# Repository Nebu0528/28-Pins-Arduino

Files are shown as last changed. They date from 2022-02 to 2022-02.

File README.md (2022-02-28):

# 28-Pins-Arduino!
Created a Replica of an Arduino Uno Board with modifications (listed below)

●	Utilized Altium Designer to create schematic, 3D components, PCB model and enhanced board by adding a user button, micro-USB (to allow charging from other devices) and a DFU Disable jumper.

●	Modified 16U2 and 328P Reset Pins to be driven through an open drain buffer meaning the RESET quality has been improved and allows for debugging microcontrollers through the dWire. 

●	Documented and replicated all elements of the design process including costs, schematic, assembly drawing and 3D PCB Model. 

PDF Files can be found in the folders attached above

## PCB

## 3D Model


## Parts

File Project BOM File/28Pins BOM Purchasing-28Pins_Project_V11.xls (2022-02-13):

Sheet: Part List Report
 | Component list |  |  | 28Pins BOM Purchasing for Project [28Pins_Project_V11.PrjPcb] (PCB Document : V1I1PCB.PcbDoc)
 | Source Data From: | 28Pins_Project_V11.PrjPcb |  |  | Contact: |  |  |  | Generated by:
 | Project: | 28Pins_Project_V11.PrjPcb
 | Variant: | None |  |  |  |  |  |  | FEDEVEL
 | Report Date: | 2022-02-01 | 5:48 PM |  |  |  |  |  | http://www.fedevel.com
 | Print Date: | 2022-02-01 | 18:30:28
# | Category | Manufacturer 1 | Manufacturer Part Number 1 | #Column Name Error:' Package / Case | Description | Quantity | Supplier 1 | Supplier Part Number 1 | Supplier Order Qty 1 | Supplier Stock 1 | Supplier Unit Price 1 | Supplier Subtotal 1 | Supplier Currency 1
1 | Aluminum Electrolytic Capacitors | Panasonic | EEE-1AA101WR |  | Cap Aluminum 100uF 10V 20% (5 X 5.4mm) SMD 50mA 1000 hr 85°C T/R | 2 | Digi-Key | PCE3867CT-ND | 20 | 0 | 0.27 | 5.30 | USD
2 | Ceramic Capacitors | TDK | C2012X5R1C106M125AC |  | CERAMIC CAPACITOR, 10UF, 16V, X5R, 20%, 0805, FULL REEL; Product Range:C Series; Capacitance:10 F; Capacitance Tolerance: 20%; Dielectric Characteristic:X5R; Voltage Rating:16V; Ceramic Capacitor Case:0805 [2012 Metric]; MSL:- ;RoHS Compliant: Yes | 7 | Digi-Key | 445-4115-1-ND |  | 0
3 | Ceramic Capacitors | TDK | C2012X7R1H104K085AA |  | C Series 0805 0.1 uF 50 V ±10 % Tolerance X7R SMT Multilayer Ceramic Capacitor | 19 | Newark | 87R4037 | 190 | 12000 | 0.03 | 4.94 | USD
4 | Ceramic Capacitors | TDK | C2012X5R1E105K125AA |  | TDK - C2012X5R1E105K125AA - SMD Multilayer Ceramic Capacitor, 1 µF, 25 V, 0805 [2012 Metric], ± 10%, X5R, C Series | 1 | Digi-Key | 445-1419-1-ND | 10 | 1537 | 0.16 | 1.58 | USD
5 | Ceramic Capacitors | KEMET | C0805C180J5GACTU |  | Cap Ceramic 18pF 50V C0G 5% SMD 0805 125C Paper T/R | 4 | Digi-Key | 399-C0805C180J5GAC7800TR-ND |  | 87418 |  |  | USD
6 | LEDs | Osram Opto | LGL29K-G2J1-24-Z |  | LED Single Chip Green 570nm 20mA 2-Pin 0603 T/R | 1 | Digi-Key | 475-2709-1-ND |  | 0
7 | Uncategorized | Osram Opto | LOL29K-H2K1-24-Z |  | Smartled Orange Lc | 1 | Digi-Key | 475-2740-1-ND |  | 0
8 | Schottky Diodes | ON Semiconductor / Fairchild | BAT54HT1G |  | Small Signal Schottky Diode, Single, 30 V, 200 Ma, 800 Mv, 600 Ma, 150 C | 2 | Digi-Key | BAT54HT1GCT-ND |  | 0
9 | Ferrite Beads and Chips | TDK | MPZ2012S601AT000 |  | Ferrite Beads Multi-Layer Power 600Ohm 25% 100MHz 2A 100mOhm DCR 0805 T/R | 3 | Digi-Key | 445-2206-6-ND | 30 | 0 | 0.09 | 2.71 | USD
10 | Headers and Wire Housings | Harwin | M20-7820842 |  | 2.54mm (0.1") Pitch SIL Vertical PC Tail Socket Assembly, selective gold + tin, 8 contacts | 2 | Newark | 55K6995 | 20 | 316 | 0.42 | 8.48 | USD
11 | Headers and Wire Housings | Harwin | M20-7820646 |  | 2.54mm (0.1") Pitch SIL Vertical PC Tail Socket Assembly, tin, 6 contacts | 1 | Digi-Key | 952-1809-ND | 10 | 1020 | 1.17 | 11.70 | USD
12 | Headers and Wire Housings | Harwin | M20-7821046 |  | 2.54mm (0.1") Pitch SIL Vertical PC Tail Socket Assembly, tin, 10 contacts | 1 | Digi-Key | 952-1847-ND | 10 | 33 | 1.47 | 14.70 | USD
13 | Headers and Wire Housings | Amphenol ICC / FCI | 67997-106HLF |  | Conn Unshrouded Header HDR 6 POS 2.54mm Solder ST Top Entry Thru-Hole BergStik® Bulk | 2 | Digi-Key | 609-3393-ND | 20 | 1491 | 1.90 | 38.00 | USD
14 | USB Connectors | Amphenol ICC / FCI | 10118193-0001LF |  | FCI Right Angle Surface Mount Mount Female USB Connector; 100 V ac; 1.8A | 1 | Digi-Key | 609-4616-1-ND | 10 | 565 | 0.42 | 4.20 | USD
15 | Headers and Wire Housings | Amphenol ICC / FCI | 68000-103HLF |  | Conn Unshrouded Header HDR 3 POS 2.54mm Solder ST Top Entry Thru-Hole BergStik® Automotive Bulk | 2 | Digi-Key | 609-3461-ND | 20 | 57459 | 0.31 | 6.16 | USD
16 | Connectors | Amphenol ICC / FCI | 68602-204HLF |  | Conn Unshrouded Header HDR 4 POS 2.54mm Solder ST Top Entry Thru-Hole BergStik® Bulk | 1 | Digi-Key | 609-3369-ND | 10 | 30 | 0.29 | 2.87 | USD
17 | Headers and Wire Housings | Amphenol ICC / FCI | 68001-204HLF |  | Conn Unshrouded Header HDR 4 POS 2.54mm Solder ST Thru-Hole Bag | 1 | Digi-Key | 609-3402-ND | 10 | 9015 | 0.40 | 3.95 | USD
18 | Fixed Inductors | KEMET | L1210R2R2MDWIT |  | Inductor RF Chip Wirewound 2.2uH 20% 100KHz 1.13A 0.104Ohm DCR 1210 T/R | 1 | Digi-Key | 399-9598-1-ND | 10 | 16332 | 0.44 | 4.37 | USD
19 | Connectors | Sullins | QPC02SXGN-RC |  | 2 Position 2.54 mm Centerline Single Circuit Open Top Jumper | 3 | Digi-Key | S9337-ND | 30 | 1685454 | 0.04 | 1.22 | USD
20 | Chip SMD Resistors | Yageo | RC0805JR-07100KL |  | Res General Purpose Thick Film 0805 100k Ohm 5% 1/8W ±100ppm/°C Molded Paper T/R | 1 | Digi-Key | 311-100KARCT-ND | 10 | 7 | 0.04 | 0.36 | USD
21 | Chip SMD Resistors | Yageo | RC0805FR-07560RL |  | Res General Purpose Thick Film 0805 560 Ohm 1% 1/8W ±100ppm/°C Molded Paper T/R | 5 | Digi-Key | 311-560CRCT-ND | 50 | 1559 | 0.04 | 2.10 | USD
22 | Chip SMD Resistors | Yageo | RC0805FR-0710KL |  | Res SMD 0805 10K 1% 0.125W T.C.100PPM | 6 | Digi-Key | 311-10.0KCRTR-ND |  | 873570 |  |  | USD
23 | Chip SMD Resistors | Yageo | RC0805FR-0722RL |  | Res SMD 0805 22R 1% 0.125W T.C.100PPM | 7 | Digi-Key | 311-22.0CRTR-ND |  | 104135 |  |  | USD
24 | Chip SMD Resistors | Yageo | RC0805JR-070RL |  | RC Series 0805 0.125 W 0 Ohm Jumper Surface Mount Thick Film Chip Resistor | 4 | Digi-Key | 311-0.0ARTR-ND |  | 2348866 |  |  | USD
25 | Chip SMD Resistors | Yageo Phycomp | RC0805FR-071ML |  | Res Thick Film 0805 1M Ohm 1% 0.125W(1/8W) ±100ppm/C Pad SMD T/R | 2 | Digi-Key | 311-1.00MCRTR-ND |  | 822877 |  |  | USD
26 | Chip SMD Resistors | Yageo | RC0805FR-071KL |  | Res Thick Film 0805 1KOhm 1% 0.125W(1/8W) 100ppm/C Epoxy Pad SMD T/R | 3 | Digi-Key | 311-1.00KCRTR-ND |  | 5035485 |  |  | USD
27 | Connectors | 3M | 4828-3004-CP |  | Socket DIP 28Cnts DualWipe 0.3InSpc. PhosphorBronze Nickel KinkedTail 4800Series | 1 | Digi-Key | 3M5480-ND | 10 | 8654 | 0.76 | 7.62 | USD
28 | Pushbutton Switches | TE Connectivity | FSM4JH |  | Switch Tactile OFF (ON) SPST Round Button PC Pins 0.05A 24VDC 1.57N Thru-Hole Loose | 2 | Digi-Key | 450-1650-ND | 20 | 136581 | 0.11 | 2.26 | USD
29 | Microcontrollers | Microchip | ATMEGA328P-PU |  | ATMEGA328P-PU; 8 bit Microcontroller AVR 20MHz 1; 32kb Flash; 2kb RAM; I2C SPI 2 | 1 | Allied Electronics | 70332157 |  | 0
30 | Microcontrollers | Microchip / Atmel | ATMEGA16U2-AU |  | 8-bit AVR MCU, 16 KB, 512 Bytes, 16 MHz, 2.7 to 5.5V, TQFP-32, RoHS | 1 | Arrow Electronics | ATMEGA16U2-AU |  | 0
31 | Voltage Regulators - Linear | Texas Instruments | TL1963A-33DCQR |  | LDO Regulator Pos 3.3V 1.5A 6-Pin(5+Tab) SOT-223 T/R | 1 | Digi-Key | 296-24534-1-ND | 10 | 0 | 3.25 | 32.52 | USD
32 | Logic Gates | Texas Instruments | SN74AHC1G09DBVR |  | Single 2-input, 2-V to 5.5-V AND gate with open-drain outputs 5-SOT-23 -55 to 125 | 4 | Digi-Key | 296-29202-1-ND | 40 | 0 | 0.31 | 12.46 | USD
33 | Crystals | Abracon | ABM7-16.000MHZ-D2Y-T |  | Crystal 16MHz ±20ppm (Tol) ±30ppm (Stability) 18pF FUND 50Ohm 2-Pin Mini-CSMD T/R | 2 | Digi-Key | 535-9840-1-ND | 20 | 0 | 0.77 | 15.46 | USD
34 | Varistors | Bourns | CG0603MLC-05E |  | ESD Suppressor Multilayer Varistor 5V Automotive 2-Pin Case 0603(1608Metric) T/R | 2 | Digi-Key | CG0603MLC-05ECT-ND | 20 | 0 | 0.35 | 6.96 | USD
 |  |  |  |  |  | 97 |  |  | 580 |  |  | 189.92
Approved |  |  |  | Notes: Some parts may no longer be available at the time of this project
 |  |  |  |  |  | 10 | pcs: | Total |  | 189.92 |  | USD
 |  |  |  |  |  |  |  | Price for 1pcs |  | 18.99 |  | USD

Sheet: Project Information
Project Full Path | C:\Users\Neel Bullywon\Desktop\Desktop\UWARG Bootcamp\28Pins_Project_V11\28Pins_Project_V11.PrjPcb
Project Filename | 28Pins_Project_V11.PrjPcb
Variant Name | None
Data-Source Filename | 28Pins_Project_V11.PrjPcb
Data-Source Full Path | C:\Users\Neel Bullywon\Desktop\Desktop\UWARG Bootcamp\28Pins_Project_V11\28Pins_Project_V11.PrjPcb
Title | 28Pins BOM Purchasing for Project [28Pins_Project_V11.PrjPcb] (PCB Document : V1I1PCB.PcbDoc)
Total Quantity | 97
Report Time | 5:48 PM
Report Date | 2022-02-01
Report Date & Tine | 2022-02-01 5:48 PM
Output Name | 28Pins BOM Purchasing
Output Type | BomReport
Output Generator Name | BOM
Output Generator Description | Bill of Materials

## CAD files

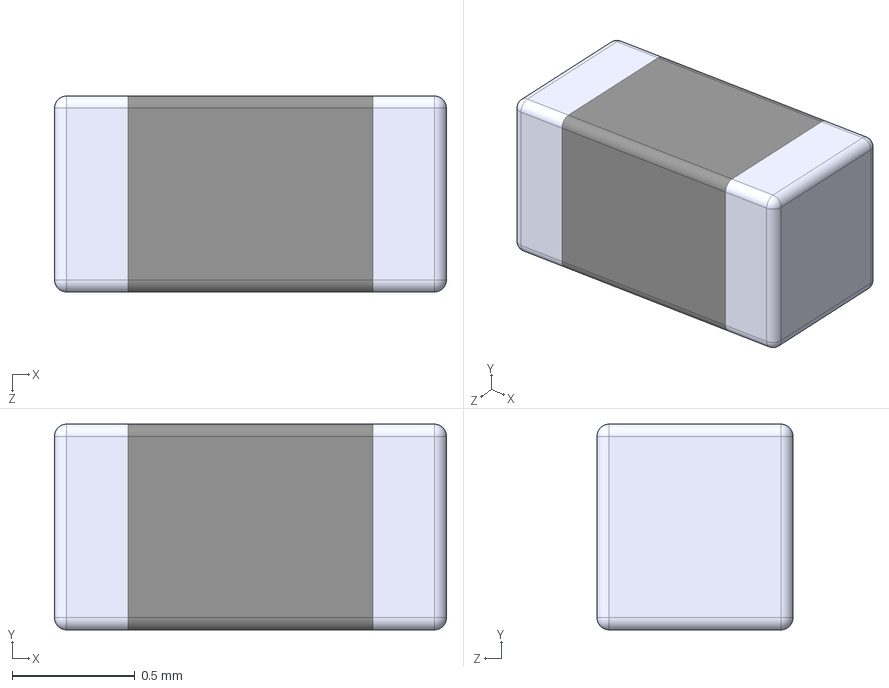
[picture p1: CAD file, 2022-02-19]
3D Component Models/R0603.step
1.60 x 0.84 x 0.8 mm

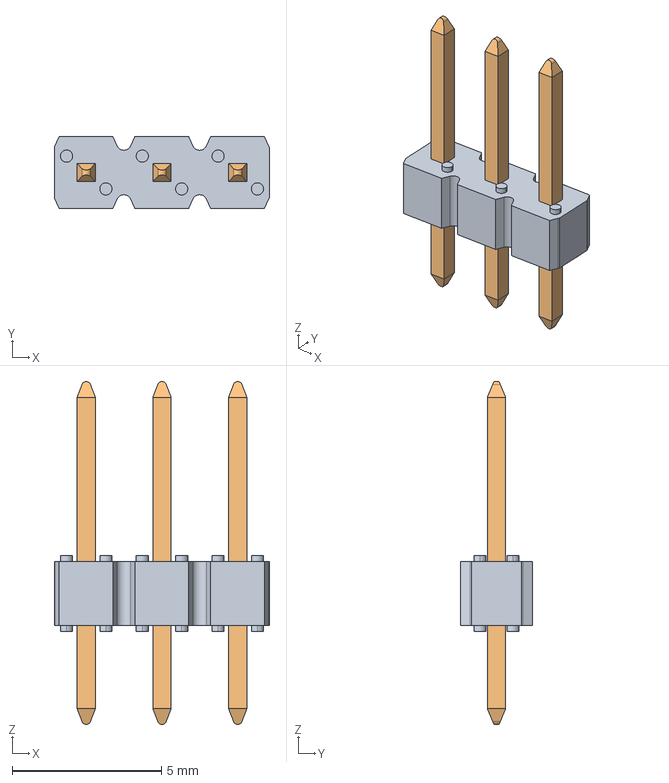
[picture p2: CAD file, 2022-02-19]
3D Component Models/HDR_1x3_White.stp
7.22 x 2.41 x 11.5 mm
77310_Y16 x 3

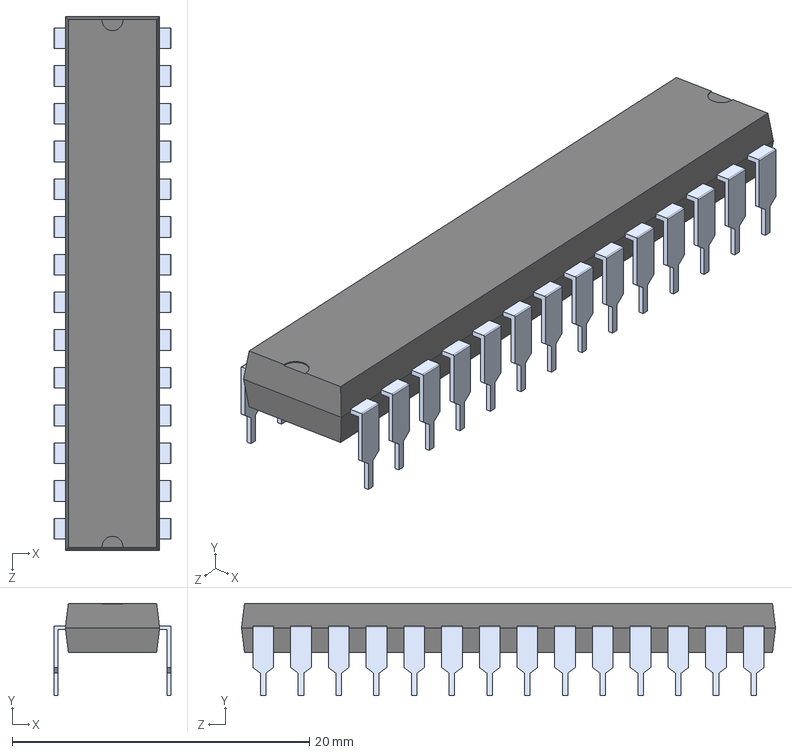
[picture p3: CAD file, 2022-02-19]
3D Component Models/28 pin dip.step
7.87 x 6.22 x 35.9 mm

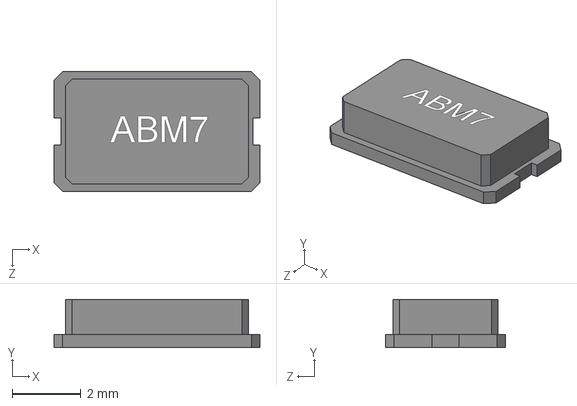
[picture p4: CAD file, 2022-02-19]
3D Component Models/ABM7.STEP
5.99 x 1.40 x 3.51 mm

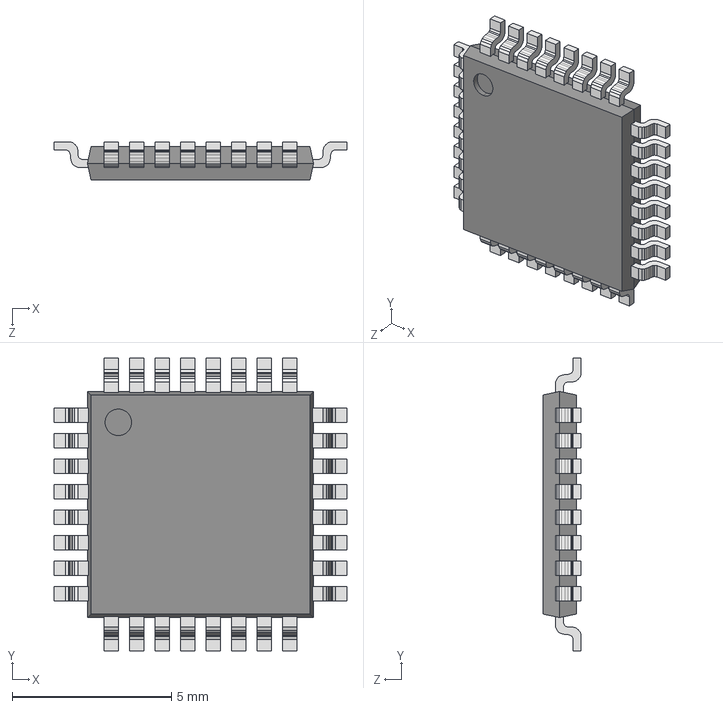
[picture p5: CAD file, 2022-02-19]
3D Component Models/tqfp32.step
9.20 x 9.20 x 1.20 mm

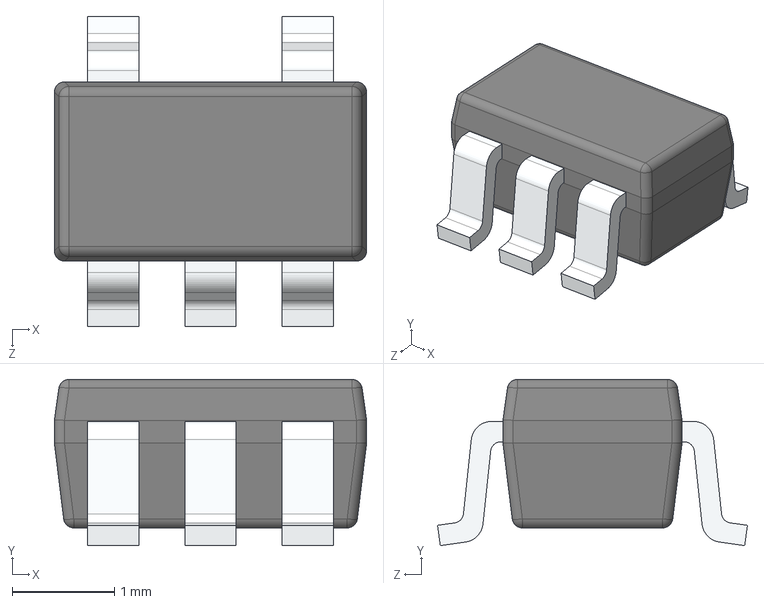
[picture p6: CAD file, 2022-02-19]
3D Component Models/DBV.step
3.05 x 1.62 x 3.03 mm

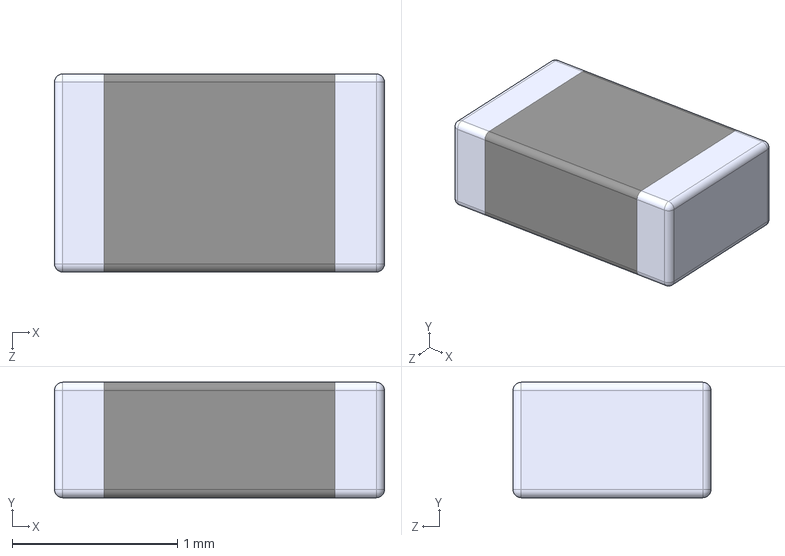
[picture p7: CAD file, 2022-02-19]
3D Component Models/RESC2012X70N EIA 0805.step
2.00 x 0.7 x 1.20 mm

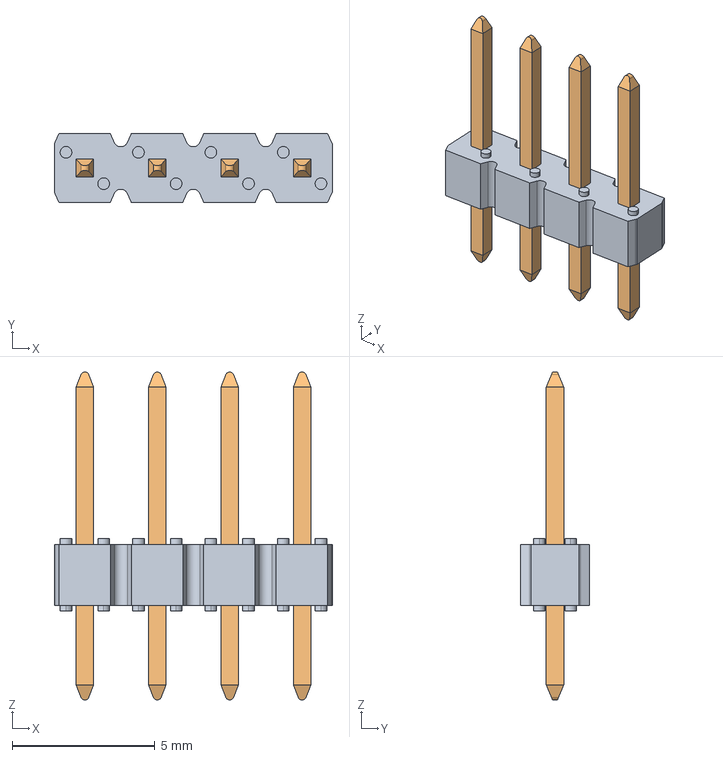
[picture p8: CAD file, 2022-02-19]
3D Component Models/HDR_1x4_White.stp
9.76 x 2.41 x 11.5 mm

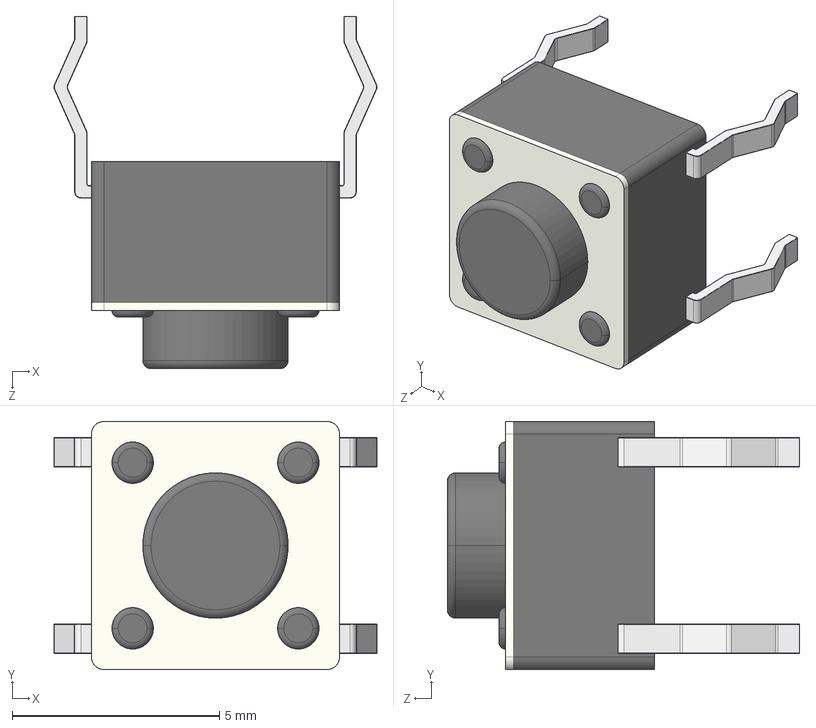
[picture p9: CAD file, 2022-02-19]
3D Component Models/FSM4JLH(1825910-5).step
7.80 x 5.99 x 8.51 mm

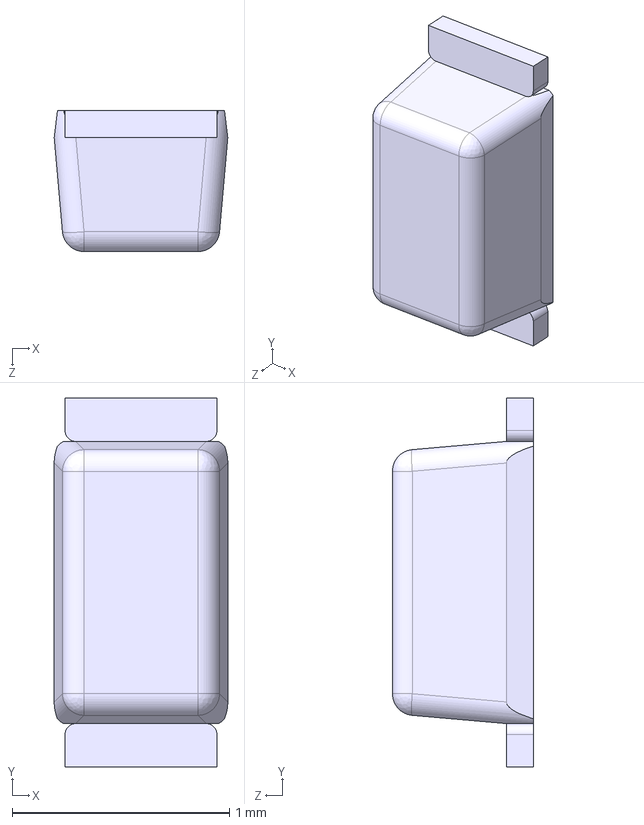
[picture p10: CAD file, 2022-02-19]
3D Component Models/LED SMD 0603.step
0.8 x 1.70 x 0.65 mm

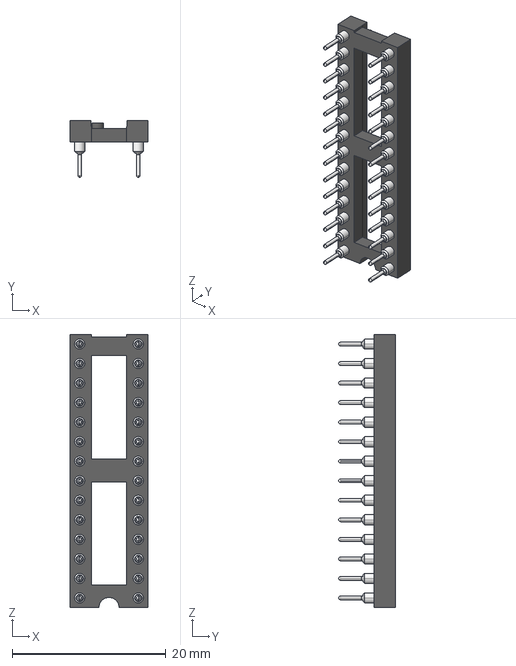
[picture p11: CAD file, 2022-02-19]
3D Component Models/dil_socket.stp
10.1 x 7.37 x 35.5 mm

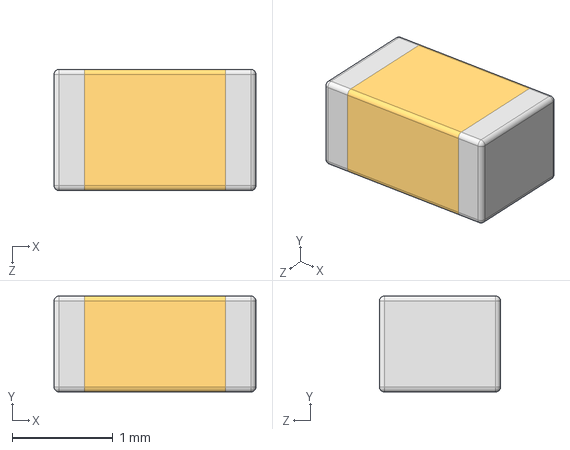
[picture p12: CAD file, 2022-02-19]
3D Component Models/CAPC2012X95N EIA 0805.step
2.00 x 0.95 x 1.20 mm

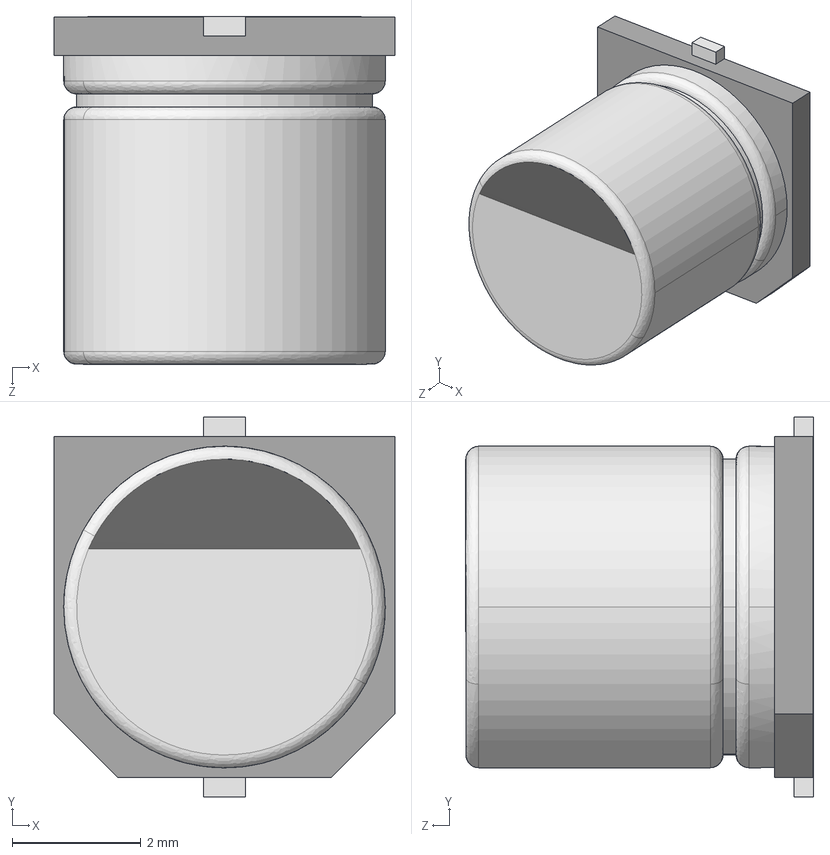
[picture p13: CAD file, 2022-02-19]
3D Component Models/capacitor size C.step
5.30 x 5.90 x 5.41 mm

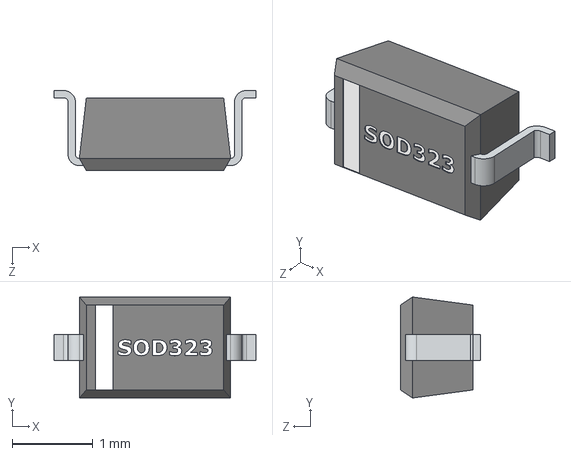
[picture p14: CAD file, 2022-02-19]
3D Component Models/SOD323.step
2.50 x 1.25 x 0.99 mm

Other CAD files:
3D Component Models/m20-7820842_asm.stp
3D Component Models/m20-7820646_asm.stp
3D Component Models/m20-7821046_asm.stp
3D Component Models/TPS73701DCQ.step
3D Component Models/961204-6404-XX.stp
3D Component Models/961206-6404-XX.stp

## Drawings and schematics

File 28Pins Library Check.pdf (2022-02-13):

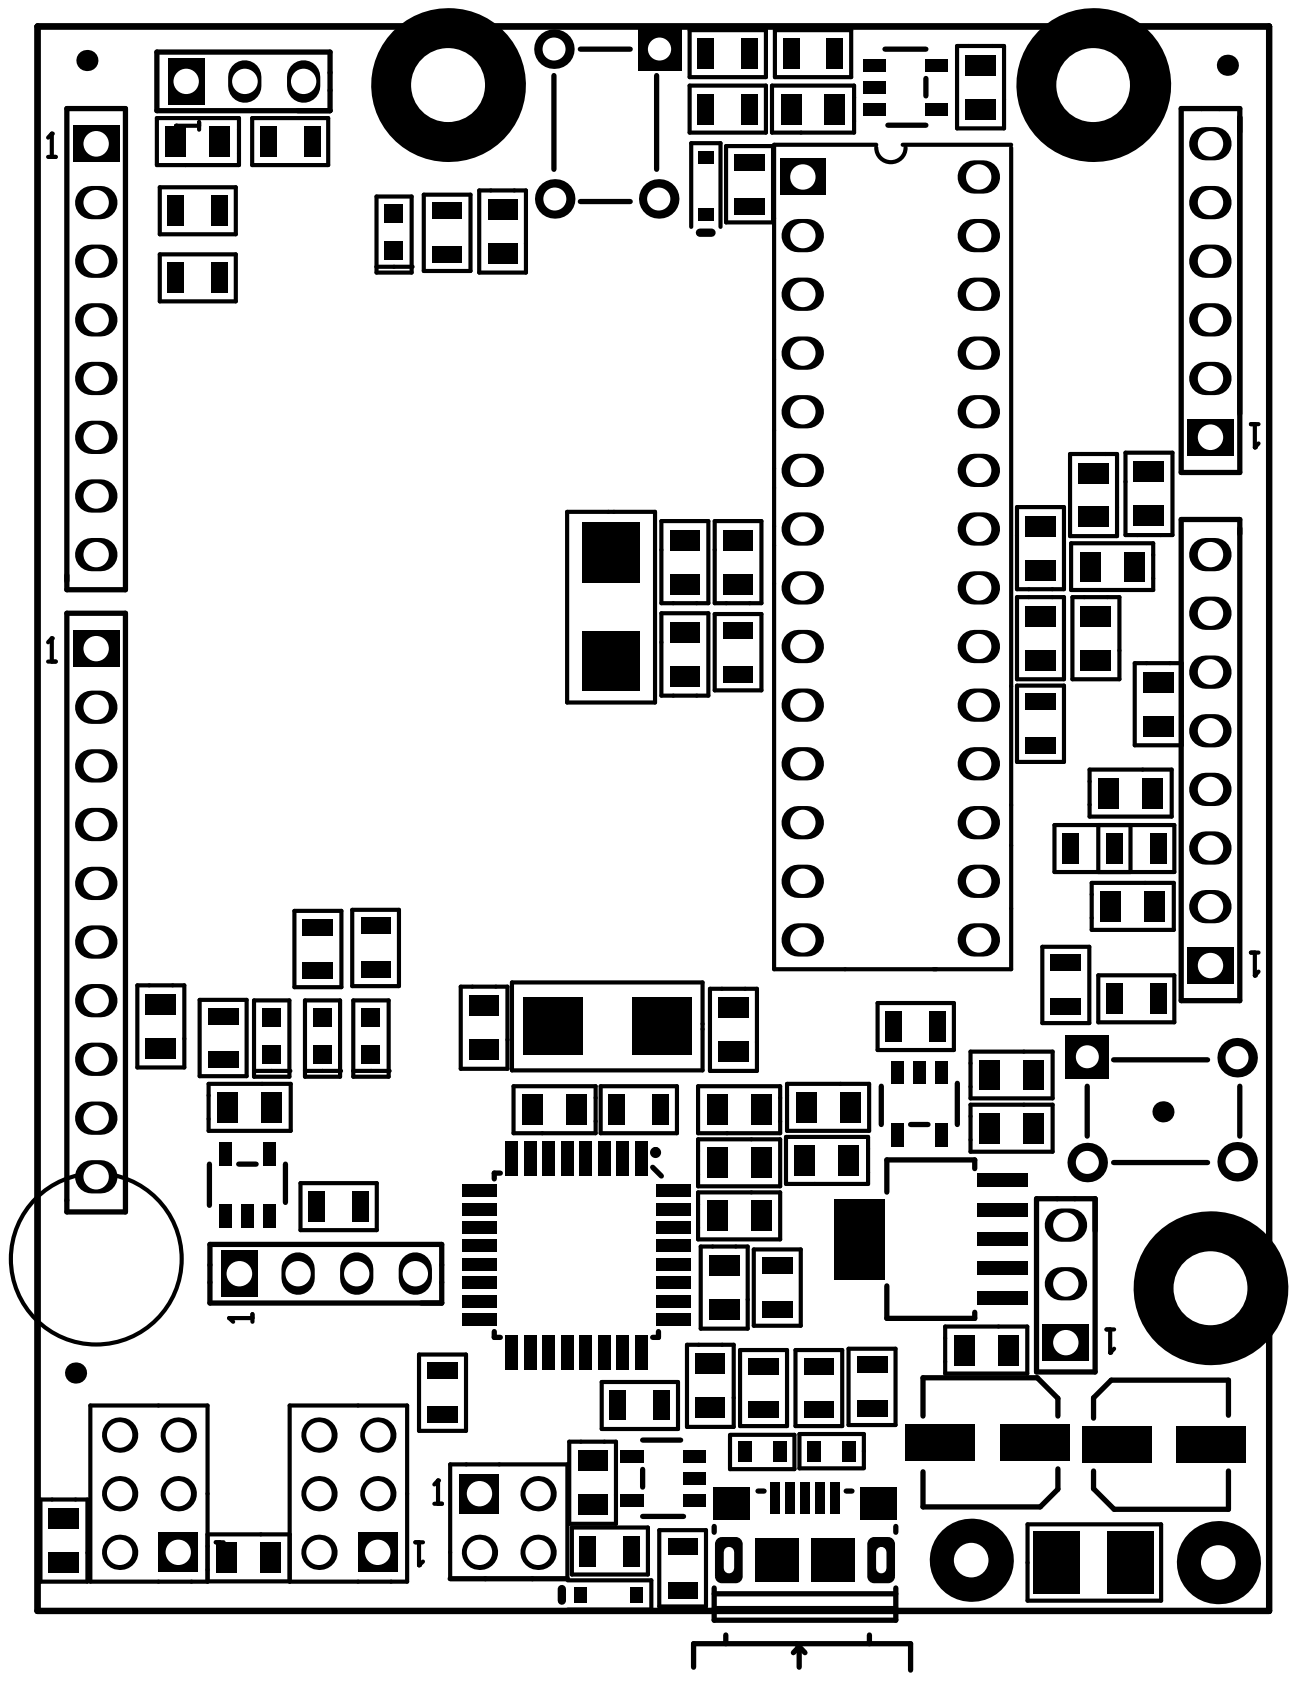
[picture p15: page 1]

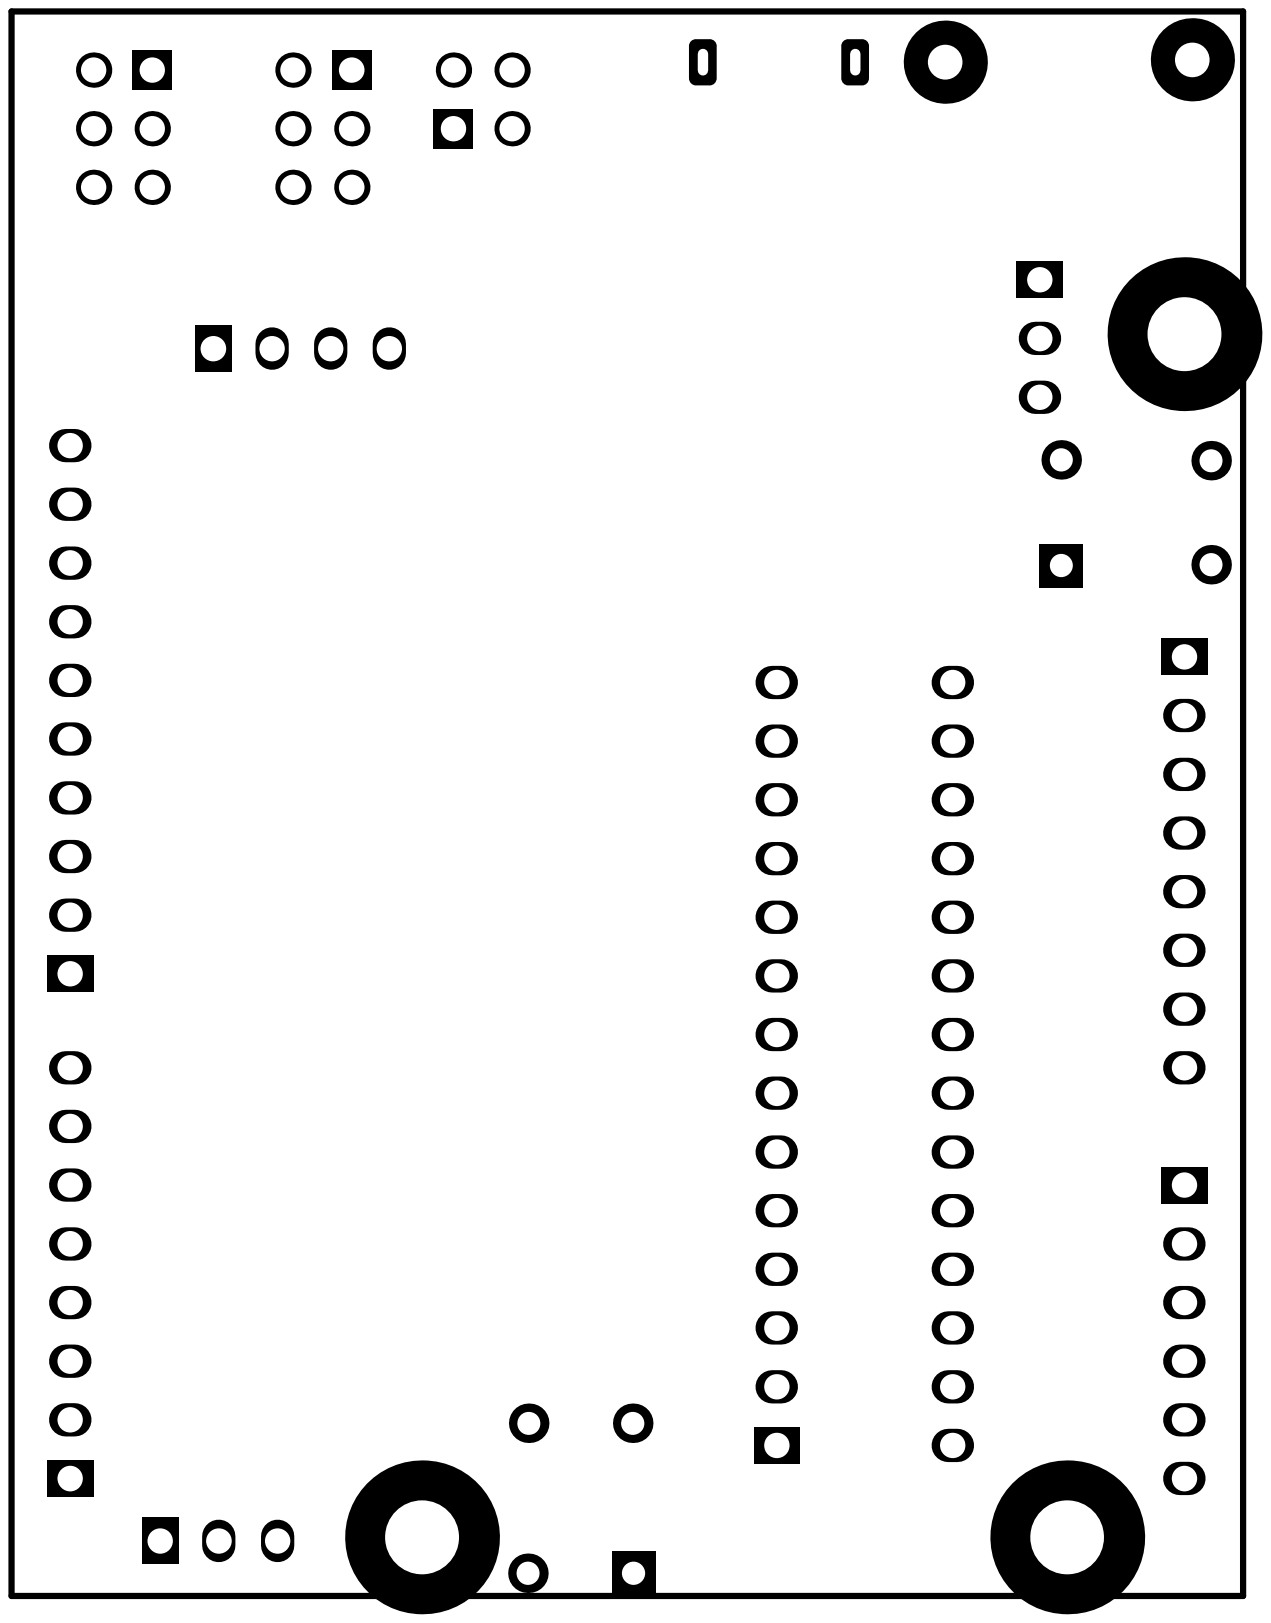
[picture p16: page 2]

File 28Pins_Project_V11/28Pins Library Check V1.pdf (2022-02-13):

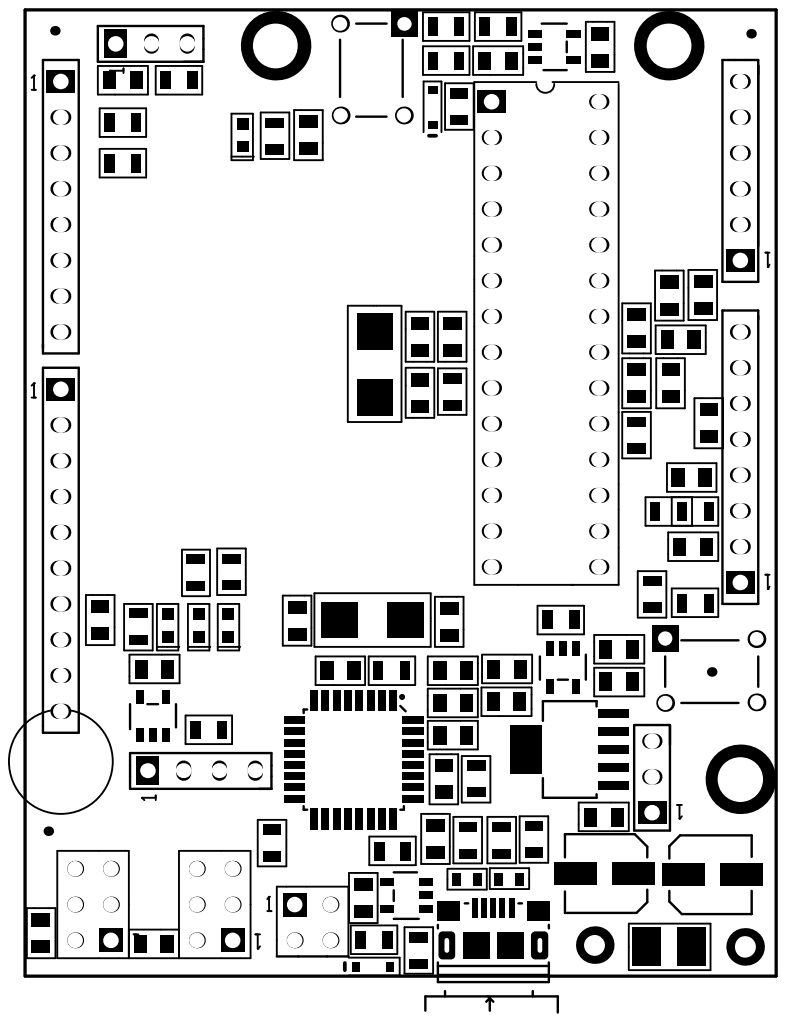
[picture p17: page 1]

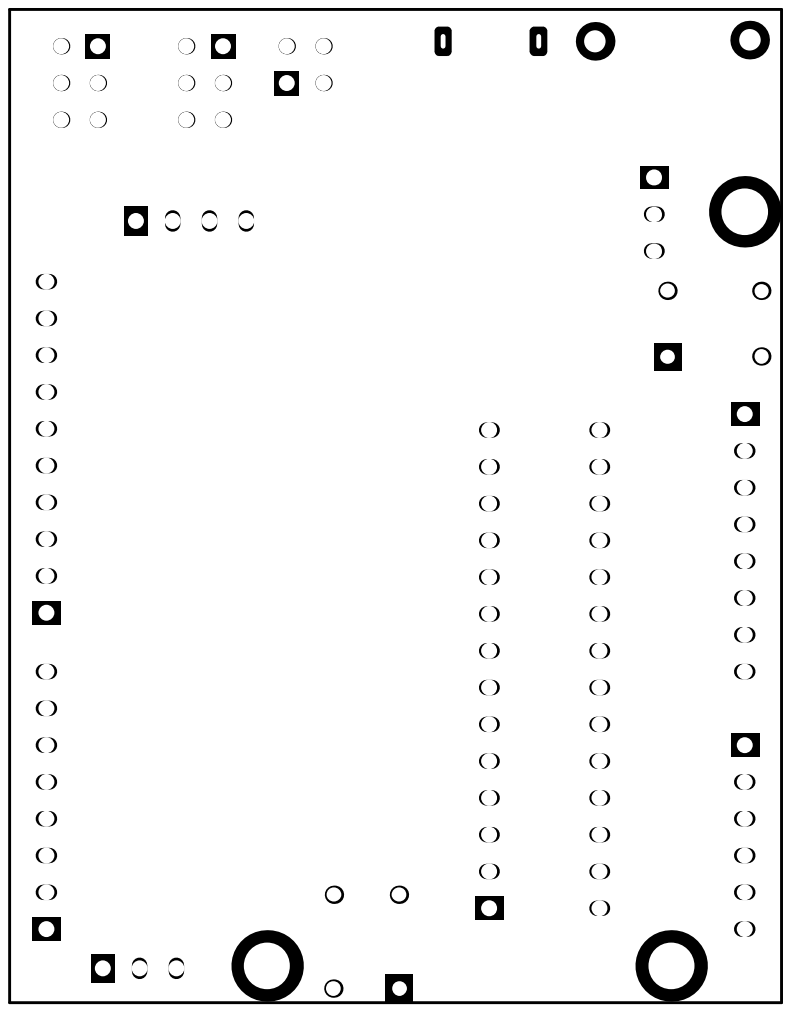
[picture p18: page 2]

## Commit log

2022-03-22 Create gerber
2022-03-22 Created Gerber Files
2022-03-22 Gerber Files
    [V1I1PCB.GBL, V1I1PCB.GBO, V1I1PCB.GBP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]
2022-03-22 Version 1 Issue 2 Revision
    [28Pins BOM Purchasing-28Pins_Project_V11.xls, 28Pins_Project_V11.PrjPcb, 28Pins_Project_V1I1 Project.SchDoc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]
2022-03-22 Re-organized files and folders
    [28Pins BOM Purchasing-28Pins_Project_V11.xls, 28Pins_Project_V11.PrjPcb, 28Pins_Project_V1I1 Project.SchDoc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]
